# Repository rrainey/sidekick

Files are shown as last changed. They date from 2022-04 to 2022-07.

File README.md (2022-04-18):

# Sidekick
**An experimental logger for skydivers**

This is a stand-alone, battery-powered data logger designed to be
carried by a skydiver during their jump.  It includes a GPS, IMU, and altitude sensors. Data from all sensors is logged onto a Micro-SD card. The logged data can be reviewed post-jump by to-be-designed software.

The current sidekick design is composed of four off-the-shelf boards:

* Adafruit Feather M0 Adalogger - https://www.adafruit.com/product/2796
* Adafruit Ultimate GPS FeatherWing - https://www.adafruit.com/product/3133
* Adafruit MPU-6050 6-DoF Accel and Gyro Sensor - STEMMA QT Qwiic - https://www.adafruit.com/product/3886
* Adafruit DPS310 Precision Barometric Pressure / Altitude Sensor - STEMMA QT / Qwiic - https://www.adafruit.com/product/4494
* 2500 mAH LiPoly 3.7V rechargeable battery 

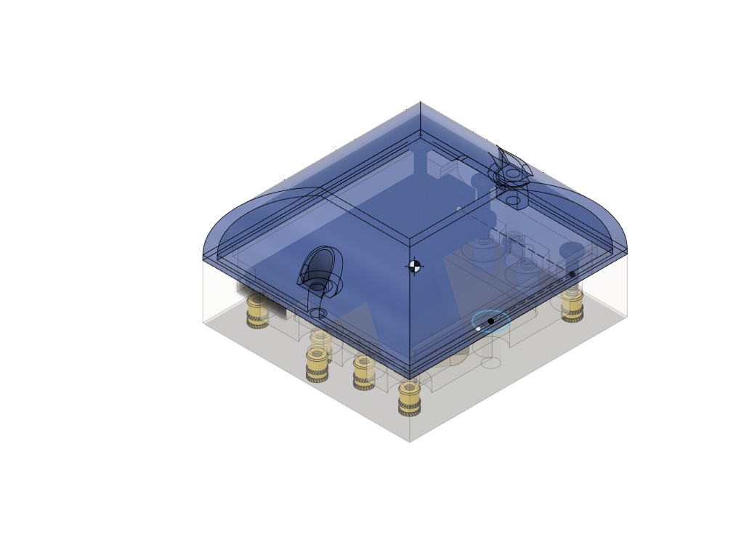
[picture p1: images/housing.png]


## Directory Structure
* **enclosure** - Fusion 360 enclosure; designed to be 3D-printed
* **src** - Arduino-based firmware for the microcontroller
* **images** - supporting images and videos

## Specifications

Power: rechargeable 2500mAh Li-Polymer battery

Storage: removable microSD card

Log file format: one log file for each jump; raw log format is an extension of NMEA0183. Details to follow.

USB micro-B connector (for recharging and programming)

Bootloader programmed via a 10-pin J-Link compatible connector; routine Arduino programming via the USB connector.

## Enclosure Notes
The enclosure is designed to be 3D printed. Tolerances between the upper enclosure, lower enclosure, and the PCB
are quite tight - printing precision will be important. Since 3D printing technologies will vary in their precision, 
you may need to scale or otherwise modify the objects to adequately match the final measurements in the original design.

For example, I printed the prototype enclosure on a MakerBot Replicator 2 (PLA) printer.  Using the default print settings
I know that an object will shrink typically by about 1% post-printing.  I set the scale to 101% to compensate for that 
in the MakerBot Desktop tooling and the end result works well.

## Credits
This PCB design uses several Adafruit Feather and Stemma QT sensor boards.  Adafruit maintains a family of excellent
microcontroller and sensor evalation boards and companion software.  Support them. They deserve it.

The enclosure for this project was designed using the personal edition of Fusion 360. Autodesk supports the Maker community
through access to this epic design tool.  Try it out.

## Disclaimer
THE SOFTWARE IS PROVIDED "AS IS", WITHOUT WARRANTY OF ANY KIND, EXPRESS OR
IMPLIED, INCLUDING BUT NOT LIMITED TO THE WARRANTIES OF MERCHANTABILITY,
FITNESS FOR A PARTICULAR PURPOSE AND NONINFRINGEMENT. IN NO EVENT SHALL THE
AUTHORS OR COPYRIGHT HOLDERS BE LIABLE FOR ANY CLAIM, DAMAGES OR OTHER
LIABILITY, WHETHER IN AN ACTION OF CONTRACT, TORT OR OTHERWISE, ARISING FROM,
OUT OF OR IN CONNECTION WITH THE SOFTWARE OR THE USE OR OTHER DEALINGS IN THE
SOFTWARE.

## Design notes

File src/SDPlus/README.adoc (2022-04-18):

= Revised SD Library for Arduino =

This library, "SDPlus", is the original Arduino SD library with a minor
modification designed to allow it to interoperate with the Arduino TinyUSB SD USB drive interface.

image:https://travis-ci.org/arduino-libraries/SD.svg?branch=master[Build Status, link=https://travis-ci.org/arduino-libraries/SD]

The SD library allows for reading from and writing to SD cards.

For more information about this library please visit us at
http://www.arduino.cc/en/Reference/SD

== License ==

 Copyright (C) 2009 by William Greiman
Copyright (c) 2010 SparkFun Electronics

This program is free software: you can redistribute it and/or modify
it under the terms of the GNU General Public License as published by
the Free Software Foundation, either version 3 of the License, or
(at your option) any later version.

This program is distributed in the hope that it will be useful,
but WITHOUT ANY WARRANTY; without even the implied warranty of
MERCHANTABILITY or FITNESS FOR A PARTICULAR PURPOSE.  See the
GNU General Public License for more details.

You should have received a copy of the GNU General Public License
along with this program.  If not, see <http://www.gnu.org/licenses/>.

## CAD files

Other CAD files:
enclosure/HOUSING.f3z

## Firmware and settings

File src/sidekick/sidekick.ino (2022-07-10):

/* 
 * This file is part of the Kick distribution (https://github.com/rrainey/sidekick
 * Copyright (c) 2022 Riley Rainey
 * 
 * Designed for use with the Sidkick prototype package which is composed of
 * 
 *   Adafruit Adalogger (Feather M0 + SD Card slot)
 *   Adafruit Ultimate GPS Featherwing
 *   Adafruit DPS310 pressure/temp. sensor board
 *   Adafruit MPU6050 IMU sensor board
 *   
 * The SD card contents are exposed as a USB Drive using the TinyUSB library.
 * The SDPlus library is a custom version of the Arduino SD library.  It is included in this
 * repo and must be manually installed as a new library in your Arduino installation to compile.
 * 
 * This project mst be compiled as a "Adafruit Feather M0" board with TinyUSB enabled.
 * 
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
 * You should have received a copy of the GNU General Public License 
 * along with this program. If not, see <http://www.gnu.org/licenses/>.
 */

#include <SPI.h>
#include <SDPlus.h>
#include <Adafruit_TinyUSB.h>

//#include <Adafruit_BME680.h>
#include <Adafruit_DPS310.h>
#include <Adafruit_MPU6050.h>
#include <Adafruit_Sensor.h>
#include <Adafruit_GPS.h>

Adafruit_USBD_MSC usb_msc;

/**
 * Driver status: IMU sensor reports use factory calibration only. Not using IMU sensor FIFO.
 * 
 * Last IMU_zero results on my prototype:
 * 
 * averaging 10000 readings each time
 * .................... [-690,-689] --> [0,3] [-1968,-1966] --> [0,19]  [1255,1257] --> [16376,16391] [129,130] --> [0,3] [29,30] --> [-1,2]  [-1,0] --> [-4,10]
 * ....................  XAccel      YAccel        ZAccel      XGyro     YGyro     ZGyro
 * [-690,-690] --> [0,5]  [-1967,-1966] --> [0,19]  [1255,1256] --> [16376,16395] [129,130] --> [0,3] [29,30] --> [-1,2]  [-1,0] --> [-4,10]
 * .................... [-690,-690] --> [0,7]  [-1967,-1966] --> [0,19]  [1255,1256] --> [16376,16395] [129,130] --> [0,3] [29,30] --> [-2,2]  [-1,0] --> [-4,10]
 * -------------- done --------------
 *
 * For my prototype use these XYZ Gyro rate offsets (rad/sec) in post-processing software: +0.07, +0.02, +0.00 ; these are not yet built into the logging code.
 */

#define APP_STRING  "Sidekick, version 0.50"
#define LOG_VERSION 1
#define NMEA_APP_STRING "$PVER,\"Sidekick, version 0.50\",50"

/*
 * Adalogger M0 hardware definitions
 * 
 * See https://learn.adafruit.com/adafruit-feather-m0-adalogger/pinouts
 */
#define VBATPIN       A7
#define RED_LED       13
#define GREEN_SD_LED   8
#define SD_CHIP_SELECT 4

/**
 * Fatal blinking light error codes (to be implemented)
 * 
 * 1 - no SD card
 * 2 - altitude sensor fail
 * 3 - IMU sensor fail
 */

/*
 * Operating mode is compiled into the binary image.
 * 
 */
#define OPS_FLIGHT        0  // normal mode; altimeter changes used to detect motion and start/stop logging
#define OPS_STATIC_TEST   1  // for testing; time based simulation of altitude changes (full test run takes 19 minutes from boot to complete)
#define OPS_GROUND_TEST   2  // for testing; GPS-tracked horizontal motion replaces altitude changes for log control

#define OPS_MODE OPS_FLIGHT

int g_nOpMode = OPS_MODE;

#if (OPS_MODE == OPS_STATIC_TEST) 
//#include "1976AtmosphericModel.h"

//sim1976AtmosphericModel g_atm;

#endif

void startLogFileFlushing();
void stopLogFileFlushing();
void flushLog();

#define TEST_SPEED_THRESHOLD_KTS     6.0
#define OPS_HDOT_THRESHOLD_FPM       300
#define OPS_HDOT_LAND_THRESHOLD_FPM  100

/*
 * Minutes to milliseconds
 */
#define MINtoMS(x) (x * 60 * 1000)

/*
 * A fresh log file is automatically started when a jump begins.
 * In the normal operating mode, this is triggered when the pressure altitude indicates a climb of 300 fpm or greater.
 * The log file will include data for the climb-out as well as the actual jump - that's maybe something to optimize out
 * in a future version.
 * 
 * Generate a unique log file for each jump.
 * 
 * State 0: WAIT - estimate baseline surface elevation; compute HDOT_fps
 * 
 * State 1: IN_FLIGHT (enter this state when HDOT_fpm indicates >= 300 fpm climb), 
 *                   enable GPS (future versions), compute HDOT_fps, start logging if not already)
 *                   
 * State 2: LANDED1 (enter when abs(HDOT_fpm) < 100 fpm, start timer 1, log data), log data
 *                   
 * State 3: LANDED2  like state LANDED1 - if any conditions are violated, return to IN_FLIGHT state, 
 *                   go to WAIT state when timer 1 reaches 60 seconds, disable GPS (future versions), log data otherwise
 *                   
 * Each log file contains NMEA records along with extra sensor data records in quasi-NMEA format; two extra record types:
 * 
 *   $PENV,time_millisec,pressure_hPa,alt_m,battery_volts             // (altitude based on standard day temp/press)
 *   $PIMU,time_millisec,orix,oriy,oriz,rotx,roty,rotz                // (angles in rads, rates in rad/sec)
 * 
 * time_millisec is number of milliseconds since device boot
 */

#define STATE_WAIT       0
#define STATE_IN_FLIGHT  1
#define STATE_LANDED_1   2
#define STATE_LANDED_2   3

int nAppState;

#define BLINK_STATE_OFF     0
#define BLINK_STATE_LOGGING 1
#define BLINK_STATE_BATTERY 2

int blinkState = BLINK_STATE_OFF;

bool bBatteryAlarm = false;
float measuredBattery_volts;

/*
 * LiPoly battery is rated at 3.7V
 */
#define LOWBATT_THRESHOLD 3.55

/*
 * Estimated MSL altitude, based on standard day pressure @ sea level
 */
int nH_feet = 0;

/*
 * Estimated rate of climb (fpm)
 */
int nHDot_fpm = 0;

/*
 * Estimated ground elevation, ft
 * 
 * Estimated by sampling altitude while in WAIT state.
 */
int nHGround_feet = 0;

#define NUM_H_SAMPLES 5
int nHSample[NUM_H_SAMPLES];
int nHDotSample[NUM_H_SAMPLES];
int nNextHSample = 0;
uint32_t ulLastHSampleMillis;

boolean bFirstPressureSample = true;

/**
 * Currently unused.
 */
int computAvgHDot() {
  int i;
  int sum;
  for(i=0; i<NUM_H_SAMPLES; ++i) {
    sum += nHDotSample[i];
  }
  return sum / 5;
}

/**
 * Use pressure altitude samples to estimate rate of climb.
 * 
 * Rate of climb is re-estimated every 10 seconds.
 */
void updateHDot(float H_feet) {

  uint32_t ulMillis = millis();
  int nLastHSample_feet;
  int nInterval_ms =  ulMillis - ulLastHSampleMillis;

  /* update HDot every ten seconds */
  if (nInterval_ms > 10000) {
    if (!bFirstPressureSample) {
      if (nNextHSample == 0) {
        nLastHSample_feet = nHSample[NUM_H_SAMPLES-1];
      }
      else {
        nLastHSample_feet = nHSample[nNextHSample-1];
      }
      nHSample[nNextHSample] = H_feet;
      nHDotSample[nNextHSample] = (((long) H_feet - nLastHSample_feet) * 60000L) / nInterval_ms;
      nHDot_fpm = nHDotSample[nNextHSample];
    }
    else {
      bFirstPressureSample = false;
      nHSample[nNextHSample] = H_feet;
      nHDotSample[nNextHSample] = 0;
      nHDot_fpm = 0;
    }

    ulLastHSampleMillis = ulMillis;
    if (++nNextHSample >= NUM_H_SAMPLES) {
      nNextHSample = 0;
    }
  }
}

/*
 * I2C connection to the BME688 pressure/temp sensor
 */
//Adafruit_BME680 bme;

/*
 * I2C connection to the MPU-6050 IMU
 */
Adafruit_MPU6050 mpu;

bool mpu6050Present = false;

#define SEALEVELPRESSURE_HPA (1013.25)

Adafruit_DPS310 dps;
Adafruit_Sensor *dps_temp = dps.getTemperatureSensor();
Adafruit_Sensor *dps_pressure = dps.getPressureSensor();

#define GPSSerial Serial1
Adafruit_GPS GPS(&GPSSerial);

File logFile;
char logpath[32];

/*
 * Records last millis() time when timers were updated in
 * the main loop.
 */
uint32_t lastTime_ms = 0;

/*
 * Set up timers
 * 
 * Timer 1: used in landing state machine (OFF initially)
 * 
 * Timer 2: periodic check of battery state
 * 
 * Timer 3: blink controller for RED LED  (OFF initially)
 * 
 * Timer 4: BME sensor logging interval timer  (OFF initially)
 * 
 * Timer 5: Periodic SD-card log file flushing  (OFF initially)
 */

#define TIMER1_INTERVAL_MS 30000

bool bTimer1Active = false;
int32_t timer1_ms = 0;

#define TIMER2_INTERVAL_MS 30000

bool bTimer2Active = true;
int32_t timer2_ms = TIMER2_INTERVAL_MS;

#define TIMER3_ON_INTERVAL_MS     750
#define TIMER3_OFF_INTERVAL_1_MS  750 // off interval when signaling battery low
#define TIMER3_OFF_INTERVAL_2_MS  (3000 - TIMER3_ON_INTERVAL_MS) // off interval for flight mode

bool bTimer3Active = false;
int32_t timer3_ms = 0;

#define TIMER4_INTERVAL_MS 25  // 40Hz

bool bTimer4Active = false;
int32_t timer4_ms = 0;

#define TIMER5_INTERVAL_MS 10000

bool bTimer5Active = false;
int32_t timer5_ms = 0;

int redLEDState = LOW;

// For debugging
bool printNMEA = false;

/**
 * Control RED (blinking) LED
 * This LED is locted to the left of the USB connector on
 * the Adalogger
 */
void setBlinkState( int newState ) {

  switch ( blinkState ) {

  case BLINK_STATE_OFF:
    // Was off, now on?
    if (newState != BLINK_STATE_OFF ) {
      bTimer3Active = true;
      timer3_ms = TIMER3_ON_INTERVAL_MS;
      redLEDState = HIGH;
    }
    break;
    
  case BLINK_STATE_LOGGING:
    if (newState == BLINK_STATE_BATTERY) {
      bTimer3Active = true;
      timer3_ms = TIMER3_ON_INTERVAL_MS;
      redLEDState = HIGH;
    }
    else if (newState == BLINK_STATE_OFF) {
        bTimer3Active = false;
        redLEDState = LOW;
     }
     break;
     
  case BLINK_STATE_BATTERY:
    if (newState == BLINK_STATE_OFF) {
      bTimer3Active = false;
      redLEDState = LOW;
    }
    else {
      // update state, but let blinking logic handle the transition
    }
    break;
  }

  // Update state and LED
  blinkState = newState;
  digitalWrite( RED_LED, redLEDState );
}

char * generateLogname(char *gname) 
{
    char * result = NULL;
    int i;
    for (i=0; true; i++) {
      sprintf (gname, "log%05d.txt", i);
   
      if (!SD.exists(gname)) {
          result = gname;
          break;
      }
    }

    return result;
}

void updateTestStateMachine() {

  /**
   * State machine appropriate for ground testing
   */
  switch (nAppState) {

  case STATE_WAIT:
    if (GPS.speed >= TEST_SPEED_THRESHOLD_KTS) {

      Serial.println("Switching to STATE_IN_FLIGHT");
      
      // open log file
      generateLogname( logpath );
      logFile = SD.open( logpath, FILE_WRITE );

      logFile.println( NMEA_APP_STRING );

      // log data; jump to 5HZ logging
      //GPS.sendCommand(PMTK_API_SET_FIX_CTL_5HZ);
      //GPS.sendCommand(PMTK_SET_NMEA_UPDATE_5HZ);

      // Activate altitude / battery sensor logging
      bTimer4Active = true;
      timer4_ms = TIMER4_INTERVAL_MS;

      // Activate periodic log file flushing
      startLogFileFlushing();

      // Activate "in flight" LED blinking
      setBlinkState ( BLINK_STATE_LOGGING );
      
      nAppState = STATE_IN_FLIGHT;
    }
    break;

  case STATE_IN_FLIGHT:
    {

      if (GPS.speed < TEST_SPEED_THRESHOLD_KTS) {
        Serial.println("Switching to STATE_LANDED_1");
        nAppState = STATE_LANDED_1;
        timer1_ms = TIMER1_INTERVAL_MS;
        bTimer1Active = true;
      }
    }
    break;

  case STATE_LANDED_1:
    {

      if (GPS.speed >= TEST_SPEED_THRESHOLD_KTS) {
        Serial.println("Switching to STATE_IN_FLIGHT");
        nAppState = STATE_IN_FLIGHT;
        bTimer1Active = false;
      }
      else if (bTimer1Active && timer1_ms <= 0) {
        GPS.sendCommand(PMTK_API_SET_FIX_CTL_1HZ);
        GPS.sendCommand(PMTK_SET_NMEA_UPDATE_1HZ);
        bTimer4Active = false;
        Serial.println("Switching to STATE_WAIT");
        setBlinkState ( BLINK_STATE_OFF );
        nAppState = STATE_WAIT;
        bTimer1Active = false;
        
        stopLogFileFlushing();
        logFile.close();
        
      }
      
    }
    break;

  case STATE_LANDED_2:
    {
      
      if (GPS.speed >= TEST_SPEED_THRESHOLD_KTS) {
        nAppState = STATE_IN_FLIGHT;
        bTimer1Active = false;
      }
      else if (bTimer1Active && timer1_ms <= 0) {
        GPS.sendCommand(PMTK_API_SET_FIX_CTL_1HZ);
        GPS.sendCommand(PMTK_SET_NMEA_UPDATE_1HZ);
        bTimer4Active = false;
        setBlinkState ( BLINK_STATE_OFF );
        nAppState = STATE_WAIT;
        Serial.println("Switching to STATE_WAIT");
        bTimer1Active = false;
        bTimer5Active = false;

        stopLogFileFlushing();
        logFile.close();
      }
    }
    break;
  }
}

void updateFlightStateMachine() {

  /**
   * State machine appropriate for flight
   */
  switch (nAppState) {

  case STATE_WAIT:
    if (nHDot_fpm > OPS_HDOT_THRESHOLD_FPM) {

      Serial.println("Switching to STATE_IN_FLIGHT");
      
      // open log file
      generateLogname( logpath );
      logFile = SD.open( logpath, FILE_WRITE );

      logFile.println( NMEA_APP_STRING );

      // log data; jump to 5HZ logging
      //GPS.sendCommand(PMTK_API_SET_FIX_CTL_5HZ);
      //GPS.sendCommand(PMTK_SET_NMEA_UPDATE_5HZ);

      // Activate altitude / battery sensor logging
      bTimer4Active = true;
      timer4_ms = TIMER4_INTERVAL_MS;

      // Activate periodic log file flushing
      startLogFileFlushing();

      // Activate "in flight" LED blinking
      setBlinkState ( BLINK_STATE_LOGGING );
      
      nAppState = STATE_IN_FLIGHT;
    }
    break;

  case STATE_IN_FLIGHT:
    {
      if (labs(nHDot_fpm) <= OPS_HDOT_LAND_THRESHOLD_FPM) {
        Serial.println("Switching to STATE_LANDED_1");
        nAppState = STATE_LANDED_1;
        timer1_ms = TIMER1_INTERVAL_MS;
        bTimer1Active = true;
      }
    }
    break;

  case STATE_LANDED_1:
    {

      if (labs(nHDot_fpm) >= OPS_HDOT_THRESHOLD_FPM) {
        Serial.println("Switching to STATE_IN_FLIGHT");
        nAppState = STATE_IN_FLIGHT;
        bTimer1Active = false;
      }
      else if (bTimer1Active && timer1_ms <= 0) {
        GPS.sendCommand(PMTK_API_SET_FIX_CTL_1HZ);
        GPS.sendCommand(PMTK_SET_NMEA_UPDATE_1HZ);
        bTimer4Active = false;
        Serial.println("Switching to STATE_WAIT");
        setBlinkState ( BLINK_STATE_OFF );
        nAppState = STATE_WAIT;
        bTimer1Active = false;

        stopLogFileFlushing();
        logFile.close();
        
      }
      
    }
    break;

  case STATE_LANDED_2:
    {
      
      if (labs(nHDot_fpm) >= OPS_HDOT_THRESHOLD_FPM) {
        nAppState = STATE_IN_FLIGHT;
        Serial.println("Switching to STATE_IN_FLIGHT");
        bTimer1Active = false;
      }
      else if (bTimer1Active && timer1_ms <= 0) {
        GPS.sendCommand(PMTK_API_SET_FIX_CTL_1HZ);
        GPS.sendCommand(PMTK_SET_NMEA_UPDATE_1HZ);
        bTimer4Active = false;
        setBlinkState ( BLINK_STATE_OFF );
        nAppState = STATE_WAIT;
        Serial.println("Switching to STATE_WAIT");
        bTimer1Active = false;
        bTimer5Active = false;

        stopLogFileFlushing();
        logFile.close();
      }
    }
    break;
  }
}

/*
 * Start of USB Disk callbacks
 */

// Callback invoked when received READ10 command.
// Copy disk's data to buffer (up to bufsize) and
// return number of copied bytes (must be multiple of block size)
int32_t msc_read_cb (uint32_t lba, void* buffer, uint32_t bufsize)
{
  (void) bufsize;
  return SD.getCard().readBlock(lba, (uint8_t*) buffer) ? 512 : -1;
}

// Callback invoked when received WRITE10 command.
// Process data in buffer to disk's storage and 
// return number of written bytes (must be multiple of block size)
int32_t msc_write_cb (uint32_t lba, uint8_t* buffer, uint32_t bufsize)
{
  (void) bufsize;
  return SD.getCard().writeBlock(lba, buffer) ? 512 : -1;
}

// Callback invoked when WRITE10 command is completed (status received and accepted by host).
// used to flush any pending cache.
void msc_flush_cb (void)
{
  // nothing to do
}


/*
 * End of USB Disk callbacks
 */
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
void loop() {

  char lastNMEA[MAXLINELENGTH];
  
  uint32_t curTime_ms = millis();

  uint32_t deltaTime_ms = curTime_ms - lastTime_ms;

  if ( deltaTime_ms > 0 ) {

    /*
     * Update active timer countdowns
     */
    if (bTimer1Active) {
      timer1_ms -= deltaTime_ms;
    }
  
    if (bTimer2Active) {
      timer2_ms -= deltaTime_ms;
    }
  
    if (bTimer3Active) {
      timer3_ms -= deltaTime_ms;
    }
  
    if (bTimer4Active) {
      timer4_ms -= deltaTime_ms;
    }

    if (bTimer5Active) {
      timer5_ms -= deltaTime_ms;
    }
    
    lastTime_ms = curTime_ms;

  }

  while ( GPS.available() > 0 ) {
  
    char c = GPS.read();
  
    /*
     * Received a NMEA record terminator?  Process it.
     */
    if ( GPS.newNMEAreceived() ) {
  
      strcpy( lastNMEA, GPS.lastNMEA() );

      if (logFile) {
        logFile.print( lastNMEA );
        flushLog();
      }
  
      if ( printNMEA ) {
        Serial.print( lastNMEA );
      }
  
      /*
       * Parse this latest arriving NMEA record. This will update appropriate state
       * variables in the GPS object. Calling GPS.lastNMEA() also has the effect of clearing the
       * flag indicating a new record arrived.
       */
      if (!GPS.parse( lastNMEA )) {
        // message not useful to us, or (less likely) had invalid checksum
      }
  
    }

  }

  /*
   * Processing tasks below outside of the
   * GPS NMEA processing loop.
   */
   
  if (g_nOpMode == OPS_FLIGHT || g_nOpMode == OPS_STATIC_TEST) {
    updateFlightStateMachine();
  }
  else {
    updateTestStateMachine();
  }
  
 /*
  * Sample altitide (or simulate altitude changes if we are testing)
  * Log it.
  */
  sampleAndLogAltitude();

  /*
   * RED LED Blink Logic
   * 
   * The RED LED will blink using different patterns to indicate
   * one of three states: Constant off, ON/OFF at 1.5Hz to indicates a low battery.
   * A 3-second blink is used to indicate flight mode.
   */
  if (bTimer3Active && timer3_ms <= 0) {
    
    redLEDState = (redLEDState == HIGH) ? LOW : HIGH;
    digitalWrite(RED_LED, redLEDState);

    if ( redLEDState == HIGH ) {
      timer3_ms = TIMER3_ON_INTERVAL_MS;
    }
    else {
      timer3_ms = bBatteryAlarm ? TIMER3_OFF_INTERVAL_1_MS : TIMER3_OFF_INTERVAL_2_MS;
    }
    
  }

  /*
   * Every 30 seconds, measure the battery state.
   * Blink red LED if low.
   */
  if (bTimer2Active && timer2_ms <= 0) {
    
    timer2_ms = TIMER2_INTERVAL_MS;
    
    measuredBattery_volts = analogRead(VBATPIN);
    measuredBattery_volts *= 2;    // we divided by 2, so multiply back
    measuredBattery_volts *= 3.3;  // Multiply by 3.3V, our reference voltage
    measuredBattery_volts /= 1024; // convert to voltage

    if ( measuredBattery_volts <= LOWBATT_THRESHOLD ) {
      bBatteryAlarm = true;
      setBlinkState ( BLINK_STATE_BATTERY );
    }
    else {
      if ( bBatteryAlarm ) {
        setBlinkState( (nAppState != STATE_WAIT) ? BLINK_STATE_LOGGING : BLINK_STATE_OFF );
      }
      bBatteryAlarm = false;
    }
  }

  /*
   * Log IMU sensor information
   */
  if (bTimer4Active && timer4_ms <= 0) {
 
    //BMESample();
    IMU();

    timer4_ms = TIMER4_INTERVAL_MS;
  }
  
}

/*
 * We are not using a BME IC in this version of Dropkick
 */

#ifdef NOTDEF
void BMESample() {

  if (nAppState != STATE_WAIT) {
    
    if (! bme.performReading()) {
      Serial.println("Failed to perform BME888 reading :(");
      return;
    }

    if (logFile ) {
    
      logFile.print("$PENV,");
      logFile.print(millis());
      logFile.print(",");
      logFile.print(bme.temperature);
      logFile.print(",");
      logFile.print(bme.pressure / 100.0);
      logFile.print(",");
      logFile.print(bme.humidity);
      logFile.print(",");
      logFile.print(bme.readAltitude(SEALEVELPRESSURE_HPA));
      logFile.print(",");
      logFile.print(bme.gas_resistance / 1000.0);
      logFile.print(",");
      logFile.println(measuredBattery_volts);

    }
  }
}

void PressureSample() {

  if (nAppState != STATE_WAIT) {
    
    if (! bme.performReading()) {
      Serial.println("Failed to perform BME888 reading :(");
      return;
    }

    if (logFile ) {
    
      logFile.print("$PENV,");
      logFile.print(millis());
      logFile.print(",");
      logFile.print(bme.temperature);
      logFile.print(",");
      logFile.print(bme.pressure / 100.0);
      logFile.print(",");
      logFile.print(bme.humidity);
      logFile.print(",");
      logFile.print(bme.readAltitude(SEALEVELPRESSURE_HPA));
      logFile.print(",");
      logFile.print(bme.gas_resistance / 1000.0);
      logFile.print(",");
      logFile.println(measuredBattery_volts);

    }
  }
}
#endif

void startLogFileFlushing()
{
  if (! bTimer5Active) {
    timer5_ms = TIMER5_INTERVAL_MS;
    bTimer5Active = true;
  }
}

void stopLogFileFlushing()
{
  if (bTimer5Active) {
    timer5_ms = 0;
    bTimer5Active = false;
  }

  if ( logFile ) {
    logFile.flush();
  }
}

void flushLog() {
    
  if (bTimer5Active && timer5_ms <= 0) {
    
    //Serial.println( "Log flushing" );

    timer5_ms = TIMER5_INTERVAL_MS;

    if ( logFile ) {
      logFile.flush();
    }
    
  }
}

void IMU() {

  if (mpu6050Present) {
    
    sensors_event_t a, g, temp;
    mpu.getEvent(&a, &g, &temp);
    
/*
    Serial.print(g.gyro.x);
    Serial.print(",");
    Serial.print(g.gyro.y);
    Serial.print(",");
    Serial.print(g.gyro.z);
    Serial.println();
*/
  
    if (logFile) {
      logFile.print("$PIMU,");
      logFile.print(millis());
      
      logFile.print(",");
      logFile.print(a.acceleration.x);  // m/s^2
      logFile.print(",");
      logFile.print(a.acceleration.y);
      logFile.print(",");
      logFile.print(a.acceleration.z);
      
      logFile.print(",");
      logFile.print(g.gyro.x);
      logFile.print(",");
      logFile.print(g.gyro.y);
      logFile.print(",");
      logFile.print(g.gyro.z);
      logFile.println();
    }
  }
}

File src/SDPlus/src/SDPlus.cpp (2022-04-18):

/*

  SD - a slightly more friendly wrapper for sdfatlib

  This library aims to expose a subset of SD card functionality
  in the form of a higher level "wrapper" object.

  License: GNU General Public License V3
          (Because sdfatlib is licensed with this.)

  (C) Copyright 2010 SparkFun Electronics


  This library provides four key benefits:

     Including `SD.h` automatically creates a global
     `SD` object which can be interacted with in a similar
     manner to other standard global objects like `Serial` and `Ethernet`.

     Boilerplate initialisation code is contained in one method named
     `begin` and no further objects need to be created in order to access
     the SD card.

     Calls to `open` can supply a full path name including parent
     directories which simplifies interacting with files in subdirectories.

     Utility methods are provided to determine whether a file exists
     and to create a directory hierarchy.


  Note however that not all functionality provided by the underlying
  sdfatlib library is exposed.

*/

/*

  Implementation Notes

  In order to handle multi-directory path traversal, functionality that
  requires this ability is implemented as callback functions.

  Individual methods call the `walkPath` function which performs the actual
  directory traversal (swapping between two different directory/file handles
  along the way) and at each level calls the supplied callback function.

  Some types of functionality will take an action at each level (e.g. exists
  or make directory) which others will only take an action at the bottom
  level (e.g. open).

*/

#include "SDPlus.h"

namespace SDPlusLib {

  // Used by `getNextPathComponent`
#define MAX_COMPONENT_LEN 12 // What is max length?
#define PATH_COMPONENT_BUFFER_LEN MAX_COMPONENT_LEN+1

  bool getNextPathComponent(const char *path, unsigned int *p_offset,
                            char *buffer) {
    /*

      Parse individual path components from a path.

        e.g. after repeated calls '/foo/bar/baz' will be split
             into 'foo', 'bar', 'baz'.

      This is similar to `strtok()` but copies the component into the
      supplied buffer rather than modifying the original string.


      `buffer` needs to be PATH_COMPONENT_BUFFER_LEN in size.

      `p_offset` needs to point to an integer of the offset at
      which the previous path component finished.

      Returns `true` if more components remain.

      Returns `false` if this is the last component.
        (This means path ended with 'foo' or 'foo/'.)

    */

    // TODO: Have buffer local to this function, so we know it's the
    //       correct length?

    int bufferOffset = 0;

    int offset = *p_offset;

    // Skip root or other separator
    if (path[offset] == '/') {
      offset++;
    }

    // Copy the next next path segment
    while (bufferOffset < MAX_COMPONENT_LEN
           && (path[offset] != '/')
           && (path[offset] != '\0')) {
      buffer[bufferOffset++] = path[offset++];
    }

    buffer[bufferOffset] = '\0';

    // Skip trailing separator so we can determine if this
    // is the last component in the path or not.
    if (path[offset] == '/') {
      offset++;
    }

    *p_offset = offset;

    return (path[offset] != '\0');
  }



  boolean walkPath(const char *filepath, SdFile& parentDir,
                   boolean(*callback)(SdFile& parentDir,
                                      const char *filePathComponent,
                                      boolean isLastComponent,
                                      void *object),
                   void *object = NULL) {
    /*

       When given a file path (and parent directory--normally root),
       this function traverses the directories in the path and at each
       level calls the supplied callback function while also providing
       the supplied object for context if required.

         e.g. given the path '/foo/bar/baz'
              the callback would be called at the equivalent of
        '/foo', '/foo/bar' and '/foo/bar/baz'.

       The implementation swaps between two different directory/file
       handles as it traverses the directories and does not use recursion
       in an attempt to use memory efficiently.

       If a callback wishes to stop the directory traversal it should
       return false--in this case the function will stop the traversal,
       tidy up and return false.

       If a directory path doesn't exist at some point this function will
       also return false and not subsequently call the callback.

       If a directory path specified is complete, valid and the callback
       did not indicate the traversal should be interrupted then this
       function will return true.

    */


    SdFile subfile1;
    SdFile subfile2;

    char buffer[PATH_COMPONENT_BUFFER_LEN];

    unsigned int offset = 0;

    SdFile *p_parent;
    SdFile *p_child;

    SdFile *p_tmp_sdfile;

    p_child = &subfile1;

    p_parent = &parentDir;

    while (true) {

      boolean moreComponents = getNextPathComponent(filepath, &offset, buffer);

      boolean shouldContinue = callback((*p_parent), buffer, !moreComponents, object);

      if (!shouldContinue) {
        // TODO: Don't repeat this code?
        // If it's one we've created then we
        // don't need the parent handle anymore.
        if (p_parent != &parentDir) {
          (*p_parent).close();
        }
        return false;
      }

      if (!moreComponents) {
        break;
      }

      boolean exists = (*p_child).open(*p_parent, buffer, O_RDONLY);

      // If it's one we've created then we
      // don't need the parent handle anymore.
      if (p_parent != &parentDir) {
        (*p_parent).close();
      }

      // Handle case when it doesn't exist and we can't continue...
      if (exists) {
        // We alternate between two file handles as we go down
        // the path.
        if (p_parent == &parentDir) {
          p_parent = &subfile2;
        }

        p_tmp_sdfile = p_parent;
        p_parent = p_child;
        p_child = p_tmp_sdfile;
      } else {
        return false;
      }
    }

    if (p_parent != &parentDir) {
      (*p_parent).close(); // TODO: Return/ handle different?
    }

    return true;
  }



  /*

     The callbacks used to implement various functionality follow.

     Each callback is supplied with a parent directory handle,
     character string with the name of the current file path component,
     a flag indicating if this component is the last in the path and
     a pointer to an arbitrary object used for context.

  */

  boolean callback_pathExists(SdFile& parentDir, const char *filePathComponent,
                              boolean /* isLastComponent */, void * /* object */) {
    /*

      Callback used to determine if a file/directory exists in parent
      directory.

      Returns true if file path exists.

    */
    SdFile child;
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

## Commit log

2021-12-17 fix timer calculation issue
    [sidekick.ino]
2021-12-17 timer fixes
2021-12-20 fixed timer handling
2021-12-23 misc fixes; timers, logging
    [sidekick.ino]
2022-04-18 impore current enclosure and screenshot
    [HOUSING.f3z]
2022-04-18 add custom version of Arduino SD library
2022-07-10 Tweak comments around IMU gyro bias
